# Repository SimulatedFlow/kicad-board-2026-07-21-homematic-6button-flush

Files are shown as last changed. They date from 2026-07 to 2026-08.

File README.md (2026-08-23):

# 2026-07-21-homematic-6button-flush

<!-- SF-STORE-BLOCK:BEGIN -->
## 🛒 Source-available — see before you buy

This repository contains the **full design files** of a commercial hardware board. It is **source-available, not open source**: read it, evaluate it, then buy a license to use it. See **LICENSE.md (source-available, purchase required)**.

**Get it / Buy:**
- **Order on eBay** (this board, bare PCB): https://www.ebay.de/itm/398220349166
- Product page (specs, photos, price): https://simulatedflow.teufel-engineering.com/platinen/2026-07-21-homematic-6button-flush/
- eBay store — all our boards and PCB art: https://www.ebay.de/usr/simula-9
- Merch shop (dev & gaming): https://simulatedflow.myspreadshop.de
- Merch shop (Synthetica / EDM): https://synthetica.myspreadshop.de
- Direct / invoice (Simulated Flow UG): simulatedflow@gmail.com

### 📬 **Free Board Documentation & Firmware Pack**

Schematics, BOMs and example-firmware docs for our STM32 carrier boards. Get it by joining the newsletter — plus a heads-up when something new ships. Double opt-in, unsubscribe in one click, no address sharing.

👉 **[Get the free pack](https://simulatedflow.teufel-engineering.com/newsletter/hardware/?q=gh)**

_© 2026 Simulated Flow UG. All rights reserved._
<!-- SF-STORE-BLOCK:END -->

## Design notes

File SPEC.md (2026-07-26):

# Homematic 6-Taster-Unterputzmodul — Spezifikation (Entwurf)

**Stand:** 2026-07-21 · Idee von Silvan. Ziel: offenes DIY-Tastermodul, das in eine Standard-UP-Dose passt
und **wahlweise Homematic-Funk (868 MHz)** oder **Homematic IP Wired (RS485)** kann.

## 1. Formfaktor & Mechanik
- **Platine rund, Ø 49–50 mm** (passt in UP-Dose Ø60 mm, hinter 55er-Schalterrahmen Gira/Busch/JUNG-Style).
- **6 Taster: 3 links / 3 rechts**, als Wippen-/Doppeltaster-Cluster hinter dem Rahmen.
  - Umsetzung: 6× kurzhubige SMD/THT-Taster + gedruckte/gedrehte Stößel, ODER 6 Taster hinter einer
    2-fach-3-Wippen-Blende. Raster/Position an ein konkretes 55er-Wippen-Design anpassen.
- **Bauhöhe < 24 mm** inkl. Funkmodul auf der Rückseite (UP-Dose-Tiefe beachten).
- Pro Taster optional **Status-LED** (Lichtleiter zur Front) — 6× LED, über MCU/Charlieplexing oder Portexpander.

## 2. Zwei Bestückungsvarianten (gleiche Platine, unterschiedlich bestückt)
### Variante FUNK (868 MHz, klassisch Homematic/BidCoS-kompatibel)
- **CC1101-Funkmodul** (868,3 MHz) auf der **Rückseite** (SMD-Modul oder bedrahtbares Steckmodul).
  → BidCoS ist CC1101-basiert; Firmware z. B. Richtung AskSinPP (Arduino-Lib für selbstgebaute HM-Geräte).
- **Antenne:** λ/4-Draht (~86 mm) oder Helix — Platz in/hinter der Dose einplanen.
- **Stromversorgung** ist die Kernfrage (UP ohne Neutralleiter üblich):
  - a) **Batterie** (CR2032/AAA) → nur als Sender sinnvoll, MCU im Deep-Sleep, Wake per Tasterdruck.
  - b) **Kleines AC/DC-Netzteil** wenn N vorhanden (Hutschienen-frei, aber Platz/Isolationsabstände!).
  - → Empfehlung Prototyp: **Batterie-Sender** (einfachste, sicherste UP-Variante).

### Variante WIRED (Homematic IP Wired, RS485-Bus)
- **RS485-Transceiver** (MAX485/THVD1424) — HmIP Wired ist ein RS485-basierter 2-Draht-Bus mit Speisung.
- **Busspeisung** (typ. ~24 V) → **Buck-Regler auf 3,3 V** an Bord (kein Batterie-Problem).
- Bus-Klemme/Stecker klein (kein 5,08er Phoenix — UP-Platz begrenzt; JST/Federklemme).
- **Hinweis:** Das offizielle HmIP-Wired-Protokoll ist proprietär/nicht offen dokumentiert → realistischer
  Weg ist ein **generischer RS485-Modbus/eigenes Protokoll** an eine CCU/Bridge, ODER Reverse-Engineering.
  Für den ersten Bau: Bus **elektrisch** HmIP-Wired-kompatibel (RS485 + 24 V), Protokoll = eigenes/Modbus zur
  eigenen Bridge (Pi/CCU-Add-on). Ehrliche Bewertung in README aufnehmen (kein „offiziell HmIP" behaupten).

## 3. MCU-Kandidaten
- **STM32G0** (z. B. STM32G030/G031, klein, günstig, Low-Power) — bevorzugt für UP + Batterie.
- Alternativ **STM32F103** (Bluepill-Ökosystem, mehr Referenzcode), aber größer/stromhungriger.
- 6 Taster + 6 LEDs → GPIO reicht; sonst **I²C-Portexpander (PCF8575)**.

## 4. Offene Punkte / Risiken (vor Bau klären)
1. **UP-Stromversorgung** (Batterie vs. Netzteil vs. Busspeisung) — bestimmt Platinenlayout maßgeblich.
2. **HmIP-Wired-Protokoll proprietär** → ehrliche Positionierung „RS485-kompatibel, eigenes Protokoll".
3. **Funk-Zulassung/Antenne** — 868 MHz SRD-Band, Duty-Cycle beachten (nur Sender = unkritisch).
4. **Mechanik** an ein konkretes 55er-Wippen-System koppeln (Stößel-Position).
5. Sicherheitsabstände falls 230-V-Netzteil an Bord (Kriech-/Luftstrecken, besser galv. getrennt/Batterie).

## 5. Empfohlener erster Bau (MVP)
**Runde Ø50-Platine, STM32G0, 6 Taster + 6 LEDs, CC1101 auf Rückseite, Batterie (CR2032), λ/4-Draht.**
→ Reiner **Funk-Sender** (AskSinPP-Richtung), keine Netz-/Bus-Komplikation. WIRED-Variante als 2. Ausbaustufe
mit RS485 + Buck, sobald Funk-MVP steht. Danach in die KiCad-Board-Agent-Pipeline zum Auto-Bau geben.

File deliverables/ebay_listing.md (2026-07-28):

# Homematic-6Button-Flush - Leerplatine fuer STM32 Bluepill (unbestueckt/teilbestueckt, Bausatz-Basis)

Unterputz-Tastermodul (Ø55mm) mit 6 Tastern (3 links/3 rechts) für Homematic — bestückbar als 868-MHz-Funk (CC1101) ODER Homematic IP Wired (RS485-Bus).

## Highlights
- THT + SMD (Verkauf unbestueckt/teilbestueckt; schwer loetbare SMD optional fab-bestueckt)
- Passt direkt auf die STM32 'Bluepill' (2x 20-Pin-Buchsenleiste, 22,86 mm Reihenabstand)
- Schraubklemmen am Platinenrand - Kabel sauber nach aussen
- 4x M3-Befestigungsbohrungen fuer gaengige Gehaeuse
- 4-lagig (durchgehende GND- + Versorgungs-Plane, stoerarm/EMV-freundlich)

**Passendes Gehaeuse:** Standard-Unterputzdose Ø60mm; Platine rund Ø49-50mm, hinter 55er-Wippen-/Tasterrahmen; Bestück-Tiefe UP-tauglich (<24mm inkl. Funkmodul auf Rückseite)

## Einsatzzweck
Homematic-Wandtaster sind teuer und geschlossen. Ein offenes, handlötbares 55mm-UP-Modul mit 6 frei belegbaren Tastern, das wahlweise per 868-MHz-Funk (BidCoS/HmIP-kompatibler CC1101) oder über den Homematic IP Wired RS485-Bus arbeitet, gibt es als DIY-Board nicht. Passt hinter Standard-55er-Schalterrahmen (Gira/Busch/JUNG-kompatibel).

## Bestueckung (ca. 16 Bauteile laut Stueckliste)
- ANT: ANT_lambda4 (x1)
- BT1: CR2032 (x1)
- C1: 100nF (x1)
- C2: 100nF (x1)
- C3: 10uF (x1)
- J_RF: CC1101 (x1)
- J_SWD: SWD (x1)
- LED1: LED (x1)
- R_LED: 1k (x1)
- SW1: SW_Push (x1)
- SW2: SW_Push (x1)
- SW3: SW_Push (x1)
- SW4: SW_Push (x1)
- SW5: SW_Push (x1)
- SW6: SW_Push (x1)
- U1: STM32G030F6Px (x1)

## Lieferumfang
- 1x unbestueckte Leiterplatte (Fertigung auf Bestellung via PCBWay)
- Schaltplan als PDF + Bestueckungsliste (BOM als CSV) zum Download

**Preis:** 22 EUR (unbestueckte Leerplatine, zzgl. Versand)

Fertigung auf Bestellung - Lieferzeit nach PCBWay-Produktion. Versand als versicherter Warenversand.

## Anbieter / Impressum (gewerblicher Verkauf)
Simulated Flow UG (haftungsbeschränkt)
Zeller Straße 37 A, 77833 Ottersweier, Deutschland
Vertreten durch den Geschäftsführer: Simulated Flow
Registergericht: Amtsgericht Mannheim, HRB 758925
USt-IdNr.: DE463825106
E-Mail: simulatedflow@gmail.com
Web: https://simulatedflow.teufel-engineering.com

Gewerblicher Verkauf durch die Simulated Flow UG — es gelten das gesetzliche Widerrufsrecht (14 Tage) und die gesetzliche Gewährleistung.

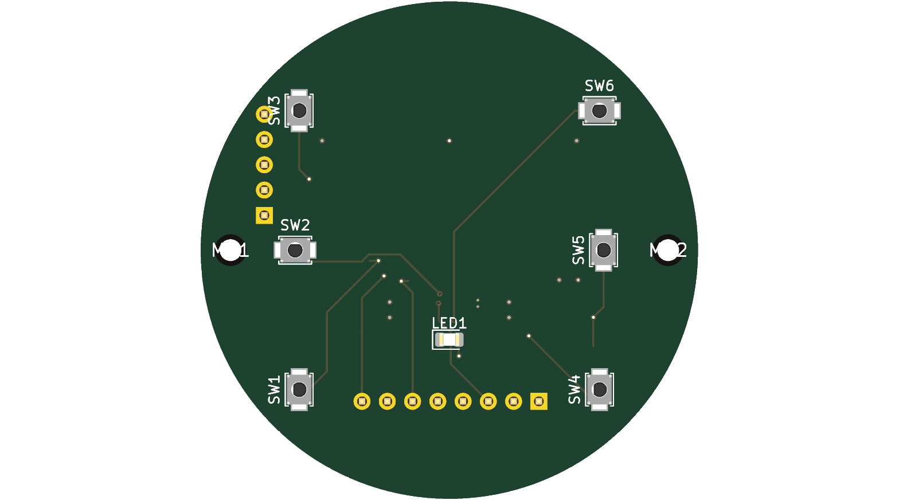
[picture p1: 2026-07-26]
deliverables/render_top.png

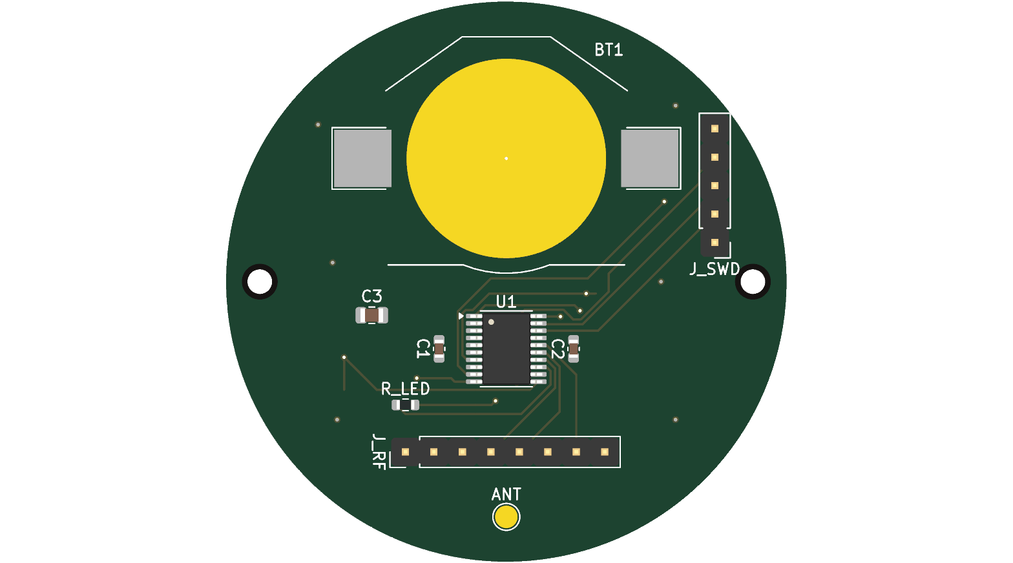
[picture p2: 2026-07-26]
deliverables/render_bottom.png

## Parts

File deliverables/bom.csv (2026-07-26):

Refs | Value | Footprint | Qty | DNP
ANT? | ANT_lambda4 | TestPoint:TestPoint_Pad_D2.0mm | 1
BT1 | CR2032 | Battery:BatteryHolder_Keystone_3002_1x2032 | 1
C1 | 100nF | Capacitor_SMD:C_0603_1608Metric | 1
C2 | 100nF | Capacitor_SMD:C_0603_1608Metric | 1
C3 | 10uF | Capacitor_SMD:C_0805_2012Metric | 1
J_RF? | CC1101 | Connector_PinHeader_2.54mm:PinHeader_1x08_P2.54mm_Vertical | 1
J_SWD? | SWD | Connector_PinHeader_2.54mm:PinHeader_1x05_P2.54mm_Vertical | 1
LED1 | LED | LED_SMD:LED_0805_2012Metric | 1
R_LED? | 1k | Resistor_SMD:R_0603_1608Metric | 1
SW1 | SW_Push | Button_Switch_SMD:SW_SPST_B3U-1000P | 1
SW2 | SW_Push | Button_Switch_SMD:SW_SPST_B3U-1000P | 1
SW3 | SW_Push | Button_Switch_SMD:SW_SPST_B3U-1000P | 1
SW4 | SW_Push | Button_Switch_SMD:SW_SPST_B3U-1000P | 1
SW5 | SW_Push | Button_Switch_SMD:SW_SPST_B3U-1000P | 1
SW6 | SW_Push | Button_Switch_SMD:SW_SPST_B3U-1000P | 1
U1 | STM32G030F6Px | Package_SO:TSSOP-20_4.4x6.5mm_P0.65mm | 1

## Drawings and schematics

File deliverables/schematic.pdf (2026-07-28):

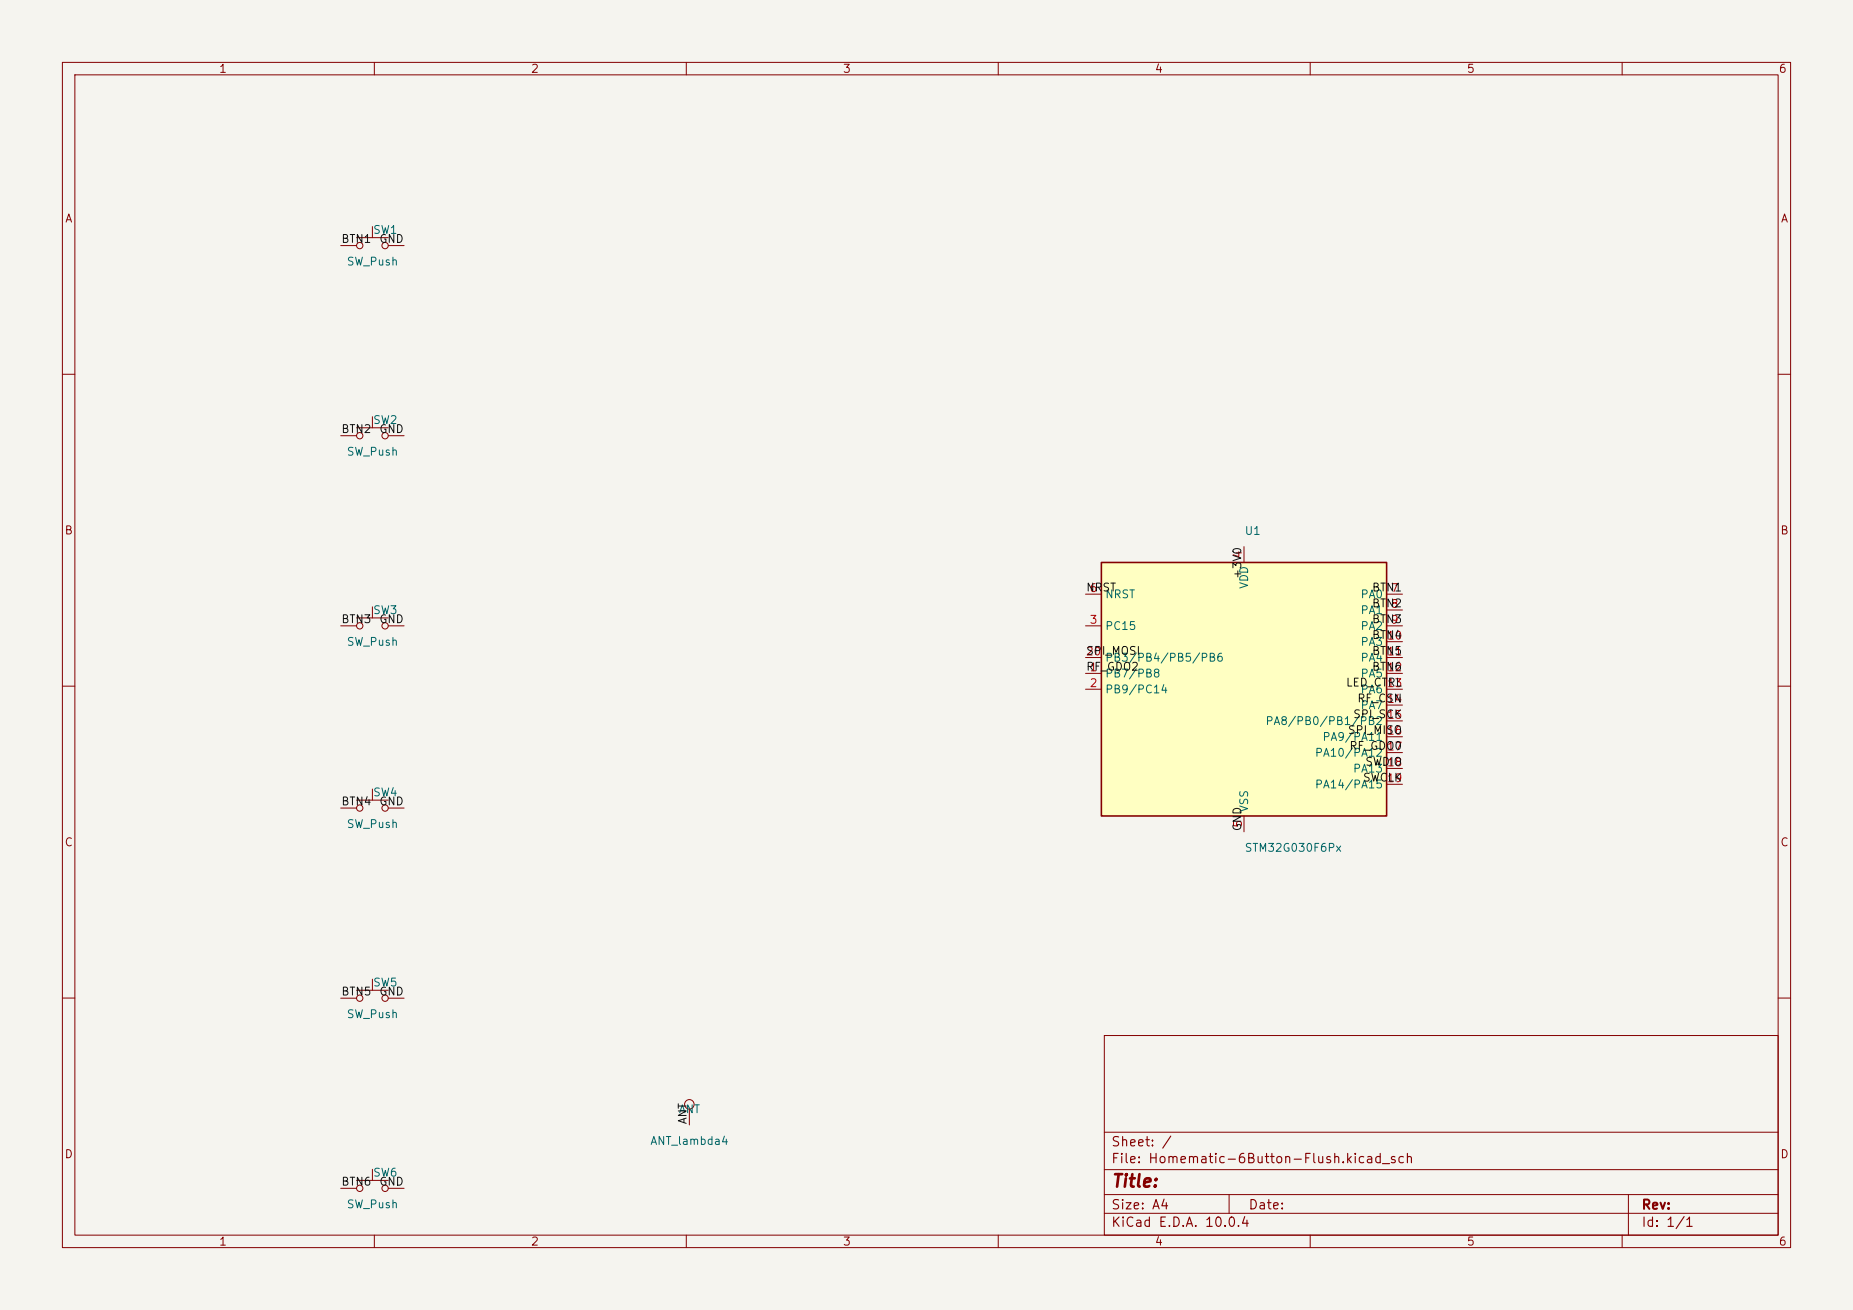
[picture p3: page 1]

Size: A4 | Rev:
KiCad E.D.A. 10.0.4 | Id: 1/1

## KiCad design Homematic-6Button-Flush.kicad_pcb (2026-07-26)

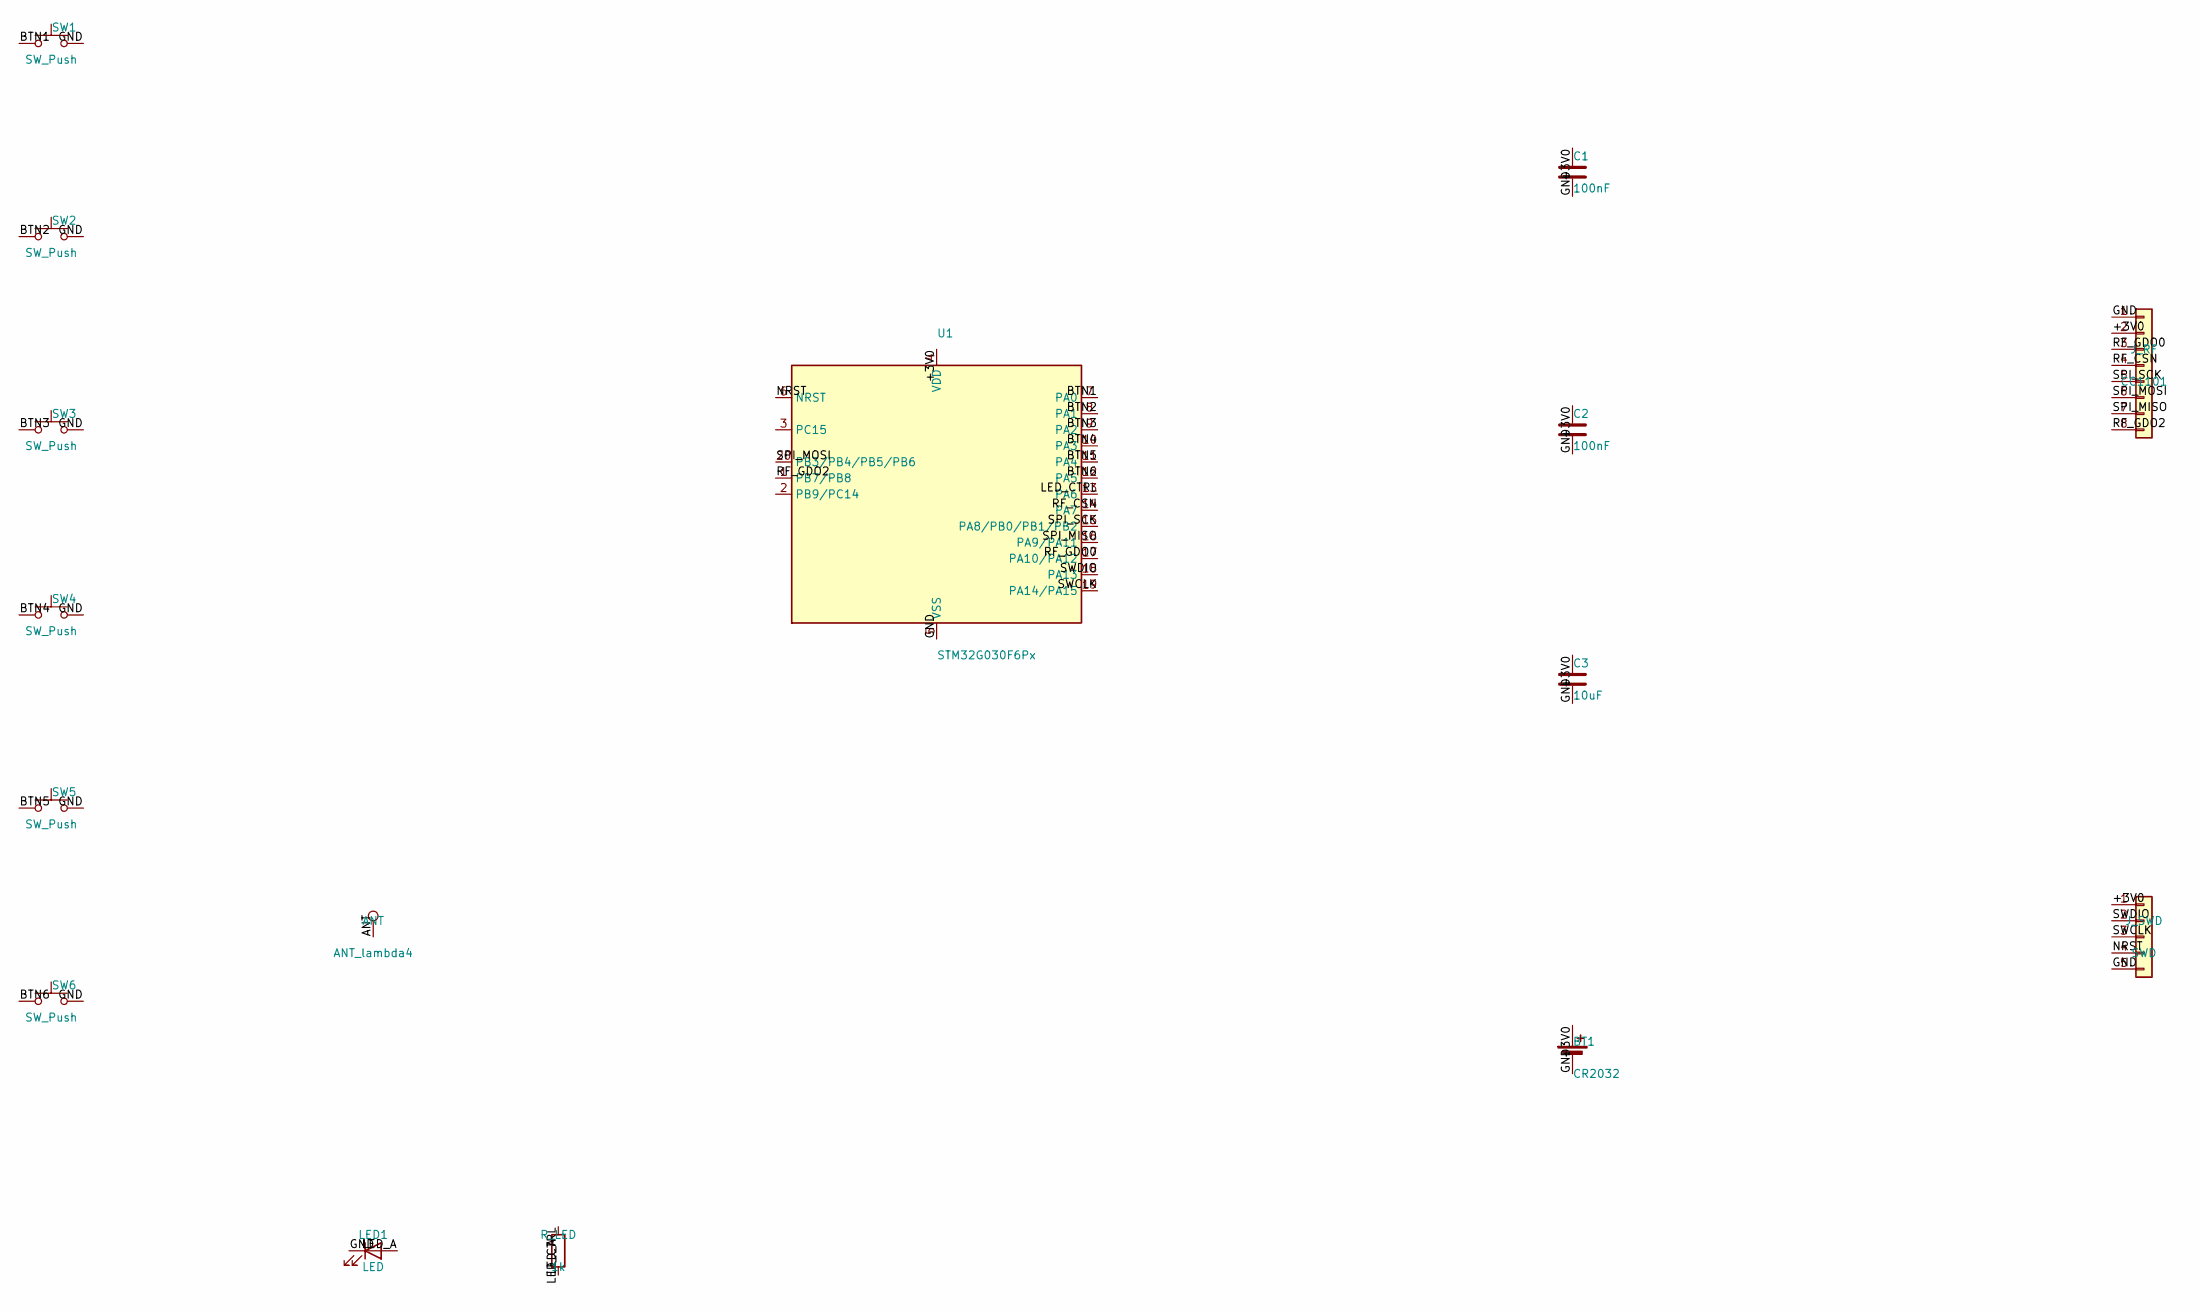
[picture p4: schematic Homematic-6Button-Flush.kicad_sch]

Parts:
ANT: ANT_lambda4; TestPoint_Pad_D2.0mm
BT1: CR2032; BatteryHolder_Keystone_3002_1x2032
C1, C2: 100nF; C_0603_1608Metric
C3: 10uF; C_0805_2012Metric
J_RF: CC1101; PinHeader_1x08_P2.54mm_Vertical
J_SWD: SWD; PinHeader_1x05_P2.54mm_Vertical
LED1: LED; LED_0805_2012Metric
R_LED: 1k; R_0603_1608Metric
SW1, SW2, SW3, SW4, SW5, SW6: SW_Push; SW_SPST_B3U-1000P
U1: STM32G030F6Px; TSSOP-20_4.4x6.5mm_P0.65mm

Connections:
+3V0: BT1.1 (+), C1.1, C2.1, C3.1, J_RF.2, J_SWD.1, U1.4 (VDD)
ANT: ANT.1
BTN1: SW1.1, U1.7 (PA0)
BTN2: SW2.1, U1.8 (PA1)
BTN3: SW3.1, U1.9 (PA2)
BTN4: SW4.1, U1.10 (PA3)
BTN5: SW5.1, U1.11 (PA4)
BTN6: SW6.1, U1.12 (PA5)
GND: BT1.2 (-), C1.2, C2.2, C3.2, J_RF.1, J_SWD.5, LED1.1 (K), SW1.2, SW2.2, SW3.2, SW4.2, SW5.2, SW6.2, U1.5 (VSS)
LED_A: LED1.2 (A), R_LED.2
LED_CTRL: R_LED.1, U1.13 (PA6)
NRST: J_SWD.4, U1.6 (NRST)
RF_CSN: J_RF.4, U1.14 (PA7)
RF_GDO0: J_RF.3, U1.17 (PA10/PA12)
RF_GDO2: J_RF.8, U1.1 (PB7/PB8)
SPI_MISO: J_RF.7, U1.16 (PA9/PA11)
SPI_MOSI: J_RF.6, U1.20 (PB3/PB4/PB5/PB6)
SPI_SCK: J_RF.5, U1.15 (PA8/PB0/PB1/PB2)
SWCLK: J_SWD.3, U1.19 (PA14/PA15)
SWDIO: J_SWD.2, U1.18 (PA13)

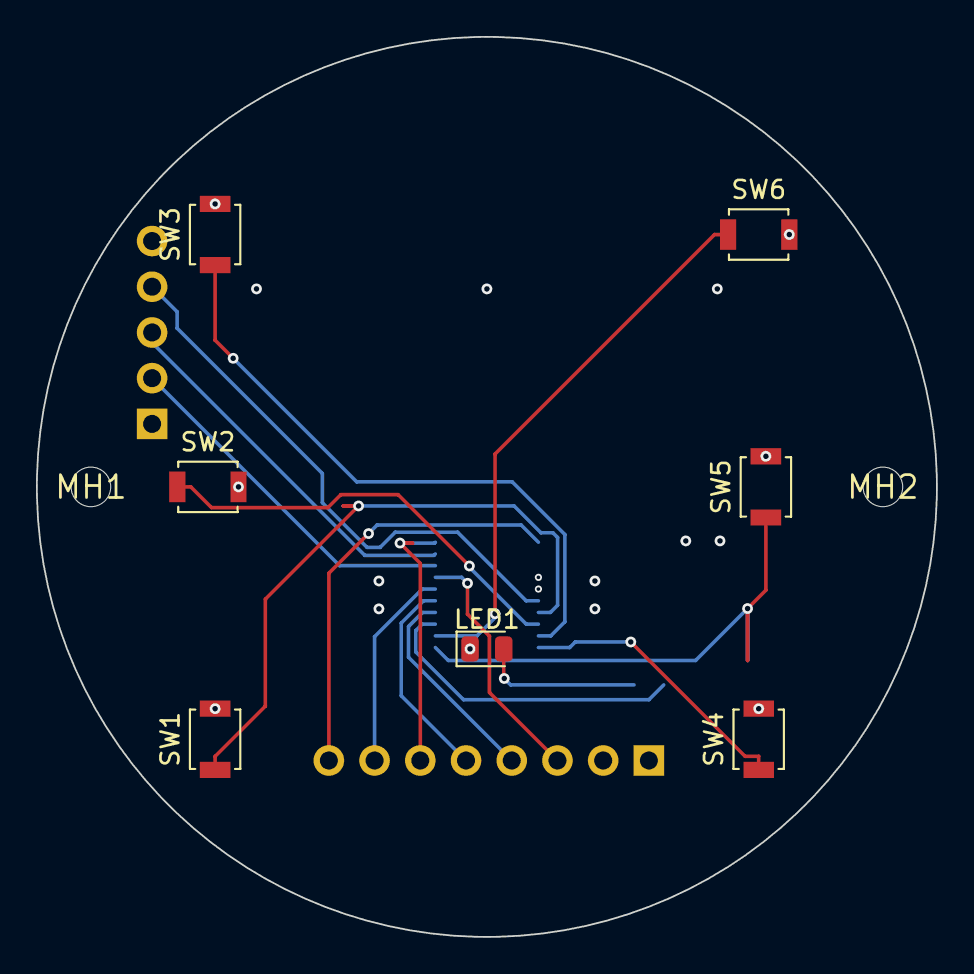
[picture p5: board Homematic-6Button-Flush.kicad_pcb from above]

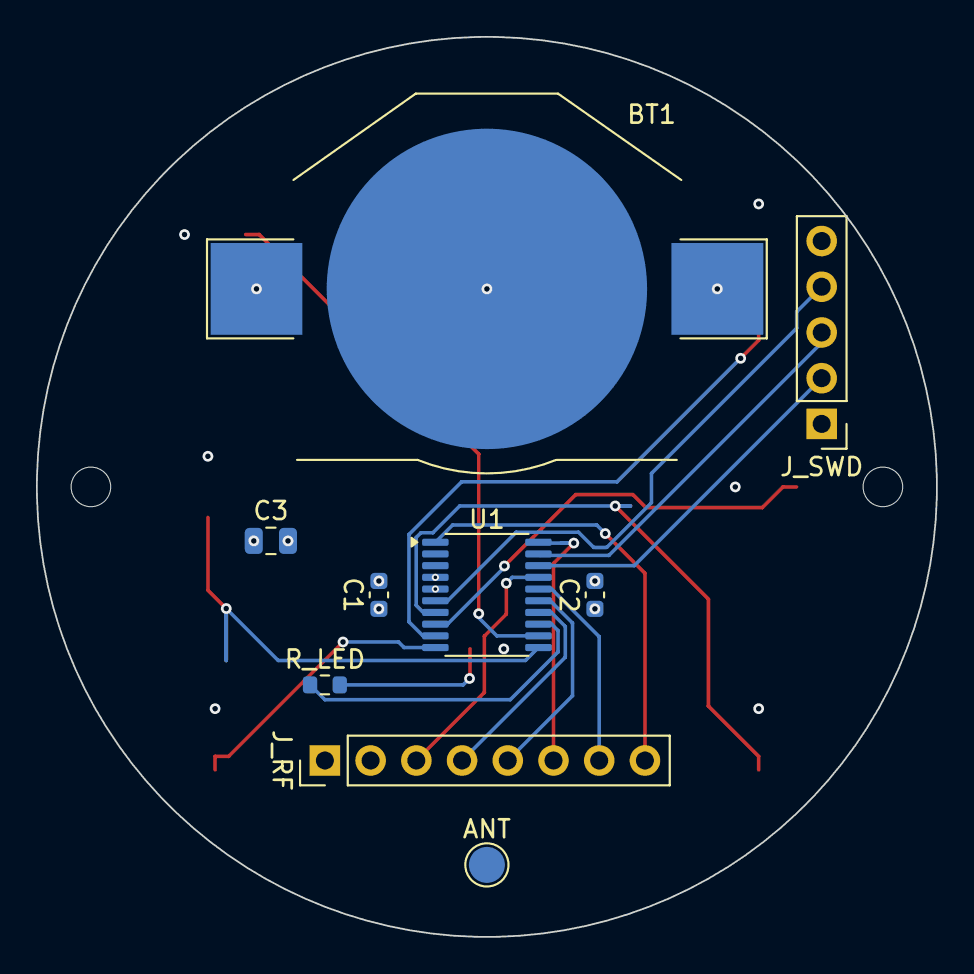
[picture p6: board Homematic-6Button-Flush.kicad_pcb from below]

Board: 4 copper layers, 50.0 x 50.0 mm, 18 parts (9 on the bottom side), 19 nets.

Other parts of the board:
MH1, MH2: MountingHole_2.2mm

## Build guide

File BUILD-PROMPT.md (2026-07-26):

```json
{
  "board_name": "Homematic-6Button-Flush",
  "one_liner": "Batteriebetriebener 868-MHz-Funk-Wandtaster (6 Taster, 3 links/3 rechts) fuer Homematic/BidCoS auf STM32G0-Basis mit steckbarem CC1101-Modul und CR2032-Knopfzelle — reiner Funk-SENDER (AskSinPP-Richtung), keine Netz-/Bus-Verbindung.",
  "market_gap": "Offener, handloetbarer DIY-Funktaster fuer Homematic. Passt hinter Standard-55er-Schalterrahmen (Gira/Busch/JUNG-Style) in eine UP-Dose. Verkauf unbestueckt/teilbestueckt.",
  "confidence": "medium",
  "price_eur": 22,
  "target_enclosure": "Standard-Unterputzdose Oe60mm; Platine rund Oe50mm, hinter 55er-Wippen-/Tasterrahmen; CC1101-Steckmodul + CR2032-Halter auf der Rueckseite (Bau-Tiefe UP-tauglich).",
  "injection_notes": "keine"
}
```

## GELOESTE SPEC-ENTSCHEIDUNGEN (Silvan 2026-07-26, MVP aus SPEC.md Kap.5)
Die offenen Punkte der SPEC sind jetzt FEST entschieden — baue GENAU diese Variante:
- **MCU:** STM32G0 (STM32G030F6Px, TSSOP-20). Klein, guenstig, Low-Power — Empfehlung der SPEC.
- **Rolle / Strom:** **Batterie-Sender (CR2032, 3 V)**. Reiner 868-MHz-Funk-Sender. **KEINE** Netzspannung, **KEIN** RS485-Bus, **KEIN** Netzteil an Bord. Das umgeht Netz-Isolation, das proprietaere HmIP-Wired-Protokoll und die UP-Netzspeisung vollstaendig (sichere UP-Variante).
- **Funk:** **CC1101 868-MHz-Modul**, steckbar ueber 1x8-Stiftleiste (Standard-CC1101-Modul-Pinout, AskSinPP-kompatibel). Das Modul traegt den Transceiver.
- **Antenne:** **λ/4-Draht (~86 mm) fuer 868 MHz.** Auf der Traegerplatine: ANT-Loetpad + rundum Antennen-Keepout (alle 4 Lagen kupferfrei), damit die Planes die Antenne nicht verstimmen.
- **Bedienung:** 6 Taster (3 links / 3 rechts) + 1 Status-LED. Taster nutzen die internen Pull-ups des STM32 (keine externen Pull-up-Widerstaende noetig).
- Sauberes, verkaufbares Board im Bluepill-Familien-Stil (unbestueckt/teilbestueckt; SMD ok; 4-Lagen mit Innen-GND-/Power-Plane).

## ⚠️ KRITISCHE BUILD-HINWEISE (ZUERST LESEN — dieses Board ist KEIN Standard-Bluepill-Carrier)
Rundes, **zweiseitig bestuecktes SMD-Board mit HF-Steckmodul**. Wichtig fuer einen DRC-sauberen, autoroutbaren Bau:
1. **Umriss RUND Oe 50,0 mm** (Zentrum 0,0), **NICHT** das 100×80-Rechteck mit 4× M3. Dazu **2× M2-Bohrungen** (Ø 2,2 mm) links/rechts fuer die Prototyp-Montage.
2. **ZWEI SEITEN, feste Zuordnung** (wie unten gelistet): **Front = F.Cu** (die 6 Taster + Status-LED, zeigen zur Schalterblende), **Rueckseite = B.Cu** (STM32, CR2032-Halter, CC1101-Steckmodul, Kondensatoren, SWD). Diese Seiten-Zuordnung nach dem Platzieren beibehalten.
3. **Falls die Pipeline `suggest_placement` (apply=true) erzwingt:** das stapelt evtl. alles in Reihen auf F.Cu und ausserhalb des Kreises — das ist hier FALSCH. Nach `suggest_placement` die kritischen Bauteile mit `move_component` ZURUECK auf ihre Seite/Koordinaten setzen (Taster 3 links/3 rechts auf F.Cu; STM32/BT1/Modul/SWD auf B.Cu innerhalb Oe50) und per `get_board_2d_view` visuell kontrollieren.
4. **ANTENNEN-KEEPOUT (Funkreichweite!):** Halbkreis-/Rechteck-Zone am oberen Rand (um das ANT-Pad bei X=0, Y=+21 mm, ca. 16×8 mm) auf **ALLEN 4 Lagen kupferfrei** — keine Tracks, keine GND-/Power-Plane-Fuellung. Die GND-Plane (In1.Cu) und die +3V0-Plane (In2.Cu) muessen diese Zone AUSSPAREN. Das CC1101-Modul (J_RF) so platzieren, dass sein Antennen-Ende zu dieser Zone zeigt.
5. **PLANE-VIAS (kritisch — haeufigster Grund fuer `unconnected` bei SMD-Boards!):** SMD-Pads liegen nur auf EINER Aussenlage und verbinden sich NICHT automatisch mit den Innen-Planes. Setze **VOR dem Signal-Routing neben JEDES GND-Pad ein Via zur GND-Plane (In1.Cu)** und neben JEDES **+3V0-Pad ein Via zur +3V0-Plane (In2.Cu)**. Danach `drc` pruefen: es duerfen KEINE GND-/+3V0-Pads mehr `unconnected` sein — ERST DANN die restlichen Signale routen.
6. Nur **~16 Bauteile** und ~17 Signalnetze (Taster, SPI zum Modul, SWD, LED) → nach korrekter Platzierung + Plane-Vias sicher autoroutbar (nur Signale auf F/B, GND/+3V0 ueber die Planes).

## BUILD-PROMPT

### Projekt-Spezifikation: Homematic-6Button-Flush (868-MHz-Funk-Wandtaster, Batterie)

Baue ein rundes, 4-lagiges UP-Tastermodul: **STM32G030** liest 6 Taster, treibt eine Status-LED und spricht per SPI ein **steckbares CC1101-868-MHz-Modul** an (Funk-Sender, AskSinPP/BidCoS-Richtung). Versorgung aus einer **CR2032-Knopfzelle (3 V)**. Reiner Sender — keine Netz-/Busverbindung.

---

### 1. Harte DFM- & Routing-Vorgaben
- **Bauteilanzahl:** ~16 Komponenten (uebersichtlich, garantiert autoroutbar).
- **Leiterbahnen & Abstaende:**
  - Signale (Taster, SPI, SWD, LED): Breite ≥ 0,3 mm, Clearance ≥ 0,25 mm.
  - Power (+3V0, GND): Breite ≥ 0,4 mm (Hauptversorgung ueber Planes).
- **Lagen-Stackup (4 Lagen, PFLICHT):**
  - **F.Cu (Front):** Signale + SMD-Pads der 6 Taster und der Status-LED.
  - **In1.Cu (Innen 1):** durchgehende **GND-Plane** (Netz `GND`), Antennen-Keepout ausgespart.
  - **In2.Cu (Innen 2):** durchgehende **+3V0-Plane** (Netz `+3V0`), Antennen-Keepout ausgespart.
  - **B.Cu (Rueckseite):** Signale + SMD-Pads von STM32, Kondensatoren, CR2032-Halter, CC1101-Modul-Header, SWD-Header.

---

### 2. Mechanik & Geometrie
- **Platinenform:** kreisrund, **Ø 50,0 mm** exakt (Zentrum X=0, Y=0). Passt hinter einen 55er-Schalterrahmen in eine UP-Dose Ø60 mm.
- **Befestigung:** 2× M2-Bohrungen (Ø 2,2 mm) bei `X=-22,0 mm, Y=0` und `X=+22,0 mm, Y=0` (je 1,0 mm kupferfreier Keepout-Ring).
- **ANT-Pad + Antennen-Keepout:** ANT-Loetpad bei `X=0, Y=+21,0 mm` (fuer den ~86 mm langen λ/4-Draht). Darum ein Keepout-Areal ca. 16×8 mm (oberer Rand) — auf **allen 4 Lagen** kupfer-/plane-frei.

---

### 3. Bestueckungsliste (BOM) & Seiten-Zuordnung

#### FRONT (F.Cu) — Bedienseite, zeigt zur Schalterblende
1. **SW1 (Taster links-oben):** SMD-Taster — *Symbol: `Switch:SW_Push`, Footprint: `Button_Switch_SMD:SW_SPST_B3U-1000P`*. Position ca. `X=-14, Y=+13`.
2. **SW2 (Taster links-mitte):** wie SW1. Position ca. `X=-14, Y=0`.
3. **SW3 (Taster links-unten):** wie SW1. Position ca. `X=-14, Y=-13`.
4. **SW4 (Taster rechts-oben):** wie SW1. Position ca. `X=+14, Y=+13`.
5. **SW5 (Taster rechts-mitte):** wie SW1. Position ca. `X=+14, Y=0`.
6. **SW6 (Taster rechts-unten):** wie SW1. Position ca. `X=+14, Y=-13`.
7. **LED1 (Status-LED):** *Symbol: `Device:LED`, Footprint: `LED_SMD:LED_0805_2012Metric`*. Zentral bei `X=0, Y=+6` (Lichtleiter zur Front).

#### RUECKSEITE (B.Cu) — Elektronik, im Inneren der UP-Dose
8. **U1 (STM32G030F6Px):** *Symbol: `MCU_ST_STM32G0:STM32G030F6Px`, Footprint: `Package_SO:TSSOP-20_4.4x6.5mm_P0.65mm`*. Zentral bei `X=0, Y=-4`.
9. **BT1 (CR2032-Knopfzellenhalter, 3 V):** *Symbol: `Device:Battery_Cell`, Footprint: `Battery:BatteryHolder_Keystone_3002_1x2032`*. Bei `X=0, Y=-12` (grosses Bauteil ~20 mm — Platz freihalten).
10. **J_RF (CC1101-868-MHz-Modul, steckbar):** 1×8-Stiftleiste — *Symbol: `Connector_Generic:Conn_01x08`, Footprint: `Connector_PinHeader_2.54mm:PinHeader_1x08_P2.54mm_Vertical`*. Nahe Oberkante bei `X=0, Y=+13`, Antennen-Ende Richtung ANT-Keepout (Y+).
11. **J_SWD (Programmier-/Debug-Header):** 1×5-Stiftleiste — *Symbol: `Connector_Generic:Conn_01x05`, Footprint: `Connector_PinHeader_2.54mm:PinHeader_1x05_P2.54mm_Vertical`*. Am Rand bei `X=-16, Y=-6`.
12. **C1 (100 nF, VDD-Entkopplung STM32):** *`Device:C`, `Capacitor_SMD:C_0603_1608Metric`*. Direkt an U1 VDD.
13. **C2 (100 nF, VCC-Entkopplung CC1101-Modul):** *`Device:C`, `Capacitor_SMD:C_0603_1608Metric`*. Nahe J_RF Pin 2.
14. **C3 (10 µF, Puffer an der Knopfzelle):** *`Device:C`, `Capacitor_SMD:C_0805_2012Metric`*. Nahe BT1 (+3V0/GND).
15. **R_LED (1 kΩ, Vorwiderstand Status-LED):** *`Device:R`, `Resistor_SMD:R_0603_1608Metric`*. Nahe LED1.
16. **ANT (λ/4-Draht-Loetpad, 868 MHz):** *Symbol: `Connector:TestPoint`, Footprint: `TestPoint:TestPoint_Pad_D2.0mm`*. Bei `X=0, Y=+21` im Antennen-Keepout (eigenes Netz `ANT`, Einzelpad fuer den ~86 mm λ/4-Draht).

*Taster brauchen KEINE externen Pull-ups (interne Pull-ups des STM32 nutzen). BOOT0/NRST bleiben auf Default (kein externer R/C noetig).*

---

### 4. Verbindungs- & Netzliste (Schematic-Leitfaden)
**Versorgung:**
- `+3V0` (Pluspol CR2032, In2.Cu-Plane): BT1 `+` → U1 `VDD`, C1, C2, C3, J_RF Pin 2 (VCC), J_SWD Pin 1 (VREF).
- `GND` (In1.Cu-Plane): BT1 `-`, U1 `VSS`, C1/C2/C3-GND, LED1-Kathode-Seite ueber R? (nein, siehe LED), J_RF Pin 1, J_SWD Pin 5, jeweils die zweite Seite der Taster SW1–SW6.

**Taster (interne Pull-ups, schalten GPIO gegen GND):**
- `BTN1..BTN6`: je ein Pin von SW1..SW6 → freier STM32-GPIO (z. B. `PA0, PA1, PA2, PA3, PA4, PA5`); der jeweils andere Taster-Pin → `GND`.

**Status-LED:**
- `LED_CTRL`: STM32-GPIO (z. B. `PA6`) → R_LED.
- `LED_A`: R_LED → LED1 Anode; LED1 Kathode → `GND`.

**CC1101-Modul (Standard-Modul-Pinout auf J_RF 1×8, SPI1):**
- J_RF Pin 1 = `GND`, Pin 2 = `+3V0`, Pin 3 = `RF_GDO0` (Interrupt, an STM32-GPIO z. B. `PB0`), Pin 4 = `RF_CSN` (an z. B. `PA8`), Pin 5 = `SPI_SCK` (an SPI1 SCK, z. B. `PB3`), Pin 6 = `SPI_MOSI` (SI, z. B. `PB5`), Pin 7 = `SPI_MISO` (SO, z. B. `PB4`), Pin 8 = `RF_GDO2` (an freien GPIO z. B. `PB1`).

**SWD (J_SWD 1×5):**
- Pin 1 = `+3V0`, Pin 2 = `SWDIO` (STM32 `PA13`), Pin 3 = `SWCLK` (STM32 `PA14`), Pin 4 = `NRST` (STM32 `NRST`), Pin 5 = `GND`.

**Antenne:**
- `ANT`: Einzel-Loetpad (ANT) — traegt den externen ~86 mm λ/4-Draht (868 MHz). Eigenes Netz, keine weitere Verbindung auf der Platine (das CC1101-Modul traegt seinen HF-Ausgang selbst; ANT-Pad ist die dokumentierte λ/4-Draht-Option). Im Antennen-Keepout platziert.

*Hinweis: Die konkreten STM32-Pin-Zuordnungen sind Vorschlaege — jeder freie GPIO ist elektrisch/DRC-gleichwertig; wichtig ist, dass alle Netze sauber verbunden sind.*

---

### 5. Arbeitsauftraege fuer die MCP-Werkzeuge (Server 'kicad')
1. **Projekt anlegen:** KiCad-Projekt `Homematic-6Button-Flush`.
2. **Schaltplan:** obige Netzliste sauber umsetzen, jedem Symbol den exakt genannten Footprint zuweisen, globale Labels fuer `+3V0`, `GND`, SPI, SWD, BTN1..6.
3. **PCB-Layout:**
   - Umriss (`Edge.Cuts`) als **Kreis Ø 50,0 mm**, Zentrum 0,0; 2× M2-Loecher bei X=±22, Y=0.
   - **Antennen-Keepout** (16×8 mm um X=0,Y=+21) auf allen 4 Lagen anlegen (Planes sparen ihn aus).
   - Bauteile nach der Front/Rueckseiten-Aufteilung platzieren (Taster/LED auf F.Cu; STM32/BT1/Modul/SWD/Cs auf B.Cu). Falls `suggest_placement` alles umwirft: kritische Teile per `move_component` zuruecksetzen, dann `get_board_2d_view` visuell pruefen (alle Bauteile IM Kreis, kein Bauteil bei 0,0 gestapelt, sichtbarer Routing-Abstand).
4. **4-Lagen-Stackup + Planes:** F.Cu/In1.Cu(GND)/In2.Cu(+3V0)/B.Cu. `add_zone` GND ueber die ganze Flaeche auf In1.Cu, `add_zone` +3V0 auf In2.Cu — **beide sparen den Antennen-Keepout aus**.
5. **Plane-Vias (PFLICHT vor dem Routing):** neben jedes GND-SMD-Pad ein Via zur In1.Cu, neben jedes +3V0-SMD-Pad ein Via zur In2.Cu. `drc` pruefen → keine GND-/+3V0-Pads mehr `unconnected`.
6. **Routing:** NUR mit MCP-Operation `autoroute` (Freerouting synchron). Nur Signale auf F.Cu/B.Cu; GND/+3V0 kommen ueber die Planes+Vias. Keine Signale auf In1/In2. KEIN `java -jar`/Bash/Hintergrundprozess — auf `autoroute` warten, bis es zurueckkehrt.
7. **DRC & Speichern:** `drc` laufen lassen, Fehler beheben (Ziel 0 severity=error), Board SPEICHERN (die geroutete `.kicad_pcb` MUSS auf Platte). Gerber/BOM/PDF/Render NICHT selbst exportieren — das macht die Pipeline (kicad-cli) danach.

*Fuehre den Bau autonom durch und fasse am Ende ehrlich zusammen: Umriss ok? ALLE Bauteile platziert (kein 0,0)? Anzahl Routing-Segmente? DRC-Status (severity=error)? .kicad_pcb gespeichert?*

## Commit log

2026-07-26 auto-backup 2026-07-26 07:26:25
    [Homematic-6Button-Flush.PREVIA-backup.kicad_pcb, Homematic-6Button-Flush.dsn, Homematic-6Button-Flush.kicad_pcb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]
2026-07-26 auto-backup 2026-07-26 08:26:26
    [Homematic-6Button-Flush.PREVIA-backup.kicad_pcb, Homematic-6Button-Flush.dsn, Homematic-6Button-Flush.kicad_pcb]
2026-07-26 auto-backup 2026-07-26 09:26:22
    [Homematic-6Button-Flush-B_Courtyard.gbr, Homematic-6Button-Flush-B_Cu.gbl, Homematic-6Button-Flush-B_Fab.gbr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]
2026-07-28 auto-backup 2026-07-28 11:26:52
    [Homematic-6Button-Flush-B_Courtyard.gbr, Homematic-6Button-Flush-B_Cu.gbl, Homematic-6Button-Flush-B_Fab.gbr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]
